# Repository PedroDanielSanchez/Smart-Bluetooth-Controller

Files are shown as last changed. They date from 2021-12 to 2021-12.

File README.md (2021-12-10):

# Smart-Bluetooth-Controller
Smart IoT Bluetooth sensors, scaling and integration gateway

# Smart Bluetooth Controller (Gateway) Asset tracking  
Smart IoT Bluetooth sensors, scaling and integration gateway

## Overview !

IoT applications that require scaling and multiple sensors several meters apart require the use of IoT gateways and integration with cloud apps and a local IoT Gateway aka controller. Bluetooth devices and beacons offer a variety of options and thus applications that allow scaling easily and cost-effectively. In this Smart IoT Bluetooth project I use different Bluetooth sensors in a system that can scale as needed. One application can be asset tracking using RSSI.

####  Features:
+ •	Measure valuable asset movement and send message if RSSI signal indicates it’s moving beyond a threshold with several asset tag sensors (Bluetooth sensors)
+•	Send notifications for RSSI if beacons move after a predefined value (Bluetooth sensors)
+•	Implement a Learning mode to register beacons to be tracked/monitored/observed
+•	Display (and refresh periodically) in a Dashboard the overall state of beacons: Total number of beacons, number of beacons that have gone into alarm state depending on a predefined value in dBm, number of beacons that have stopped to Advertise either because they’re far away, or they were stolen or the battery power drained
+•	Particle Argon for local controller
+•	OLED display
+•	GPS module to display current GPS location
+•	Button component to trigger learning (discovery) or normal operating mode.

Bluetooth devices broadcast services based upon their services. Usually asset locator BT devices broadcast every 6-8 seconds, but the time can be adjusted, and they don’t go into sleep mode. Therefore, the system will be constantly scanning for devices in the loop every 5 seconds to measure the RSSI and monitor the state of a beacon.

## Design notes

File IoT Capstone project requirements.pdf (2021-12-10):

IoT Capstone project

Smart IoT Bluetooth sensors Scaling and Integration

November 28, 2021 | Pedro D. Sanchez Amaro

Overview:

IoT applications that require scaling and multiple sensors several meters apart require the use of IoT gateways and integration with cloud apps and a local IoT controller. Bluetooth devices and beacons offer a variety of options and thus applications that allow scaling easily and costeffectively. In this Smart IoT Bluetooth project I use different Bluetooth sensors in a system that can scale as needed. One application can be asset tracking using RSSI.

Requirements:

- Measure valuable asset movement and send message if RSSI signal indicates it’s moving beyond a threshold with several asset tag sensors (Bluetooth sensors)
- Send notifications for RSSI if beacons move after a predefined value (Bluetooth sensors)
- Implement a Learning mode to register beacons to be tracked/monitored/observed.
- Display (and refresh periodically) in a Dashboard the overall state of beacons: Total number of beacons, number of beacons that have gone into alarm state depending on a predefined value in dBm, number of beacons that have stopped to Advertise either because they’re far away, or they were stolen or the battery power drained.
- Particle Argon for local controller
- OLED display
- GPS module to display current GPS location
- Button component to trigger learning (discovery) or normal operating mode.

Features:

Bluetooth devices broadcast services based upon their services. Usually asset locator BT devices broadcast every 6-8 seconds, but the time can be adjusted, and they don’t go into sleep mode. Therefore, the system will be constantly scanning for devices in the loop every 5 seconds to measure the RSSI and monitor the state of a beacon.

Implementation:

1. There will be a learning mode triggered by the push of a button to save in EEPROM the UUIDs of the beacons used so that if powered on/off, their UUIDs are there and furthermore, no other UUIDs are considered in the case that other Bluetooth devices are near passing by.
2. In the loop scan every SCAN_INTERVAL for a Bluetooth Advertising packet ( data ), look for the corresponding services and execute related callback.
a. Define an array of tracked assets (beacons), to keep track of their real time condition: stationary, moving, moving beyond a threshold system value (alarm state), non-advertising for a predefined time (“lost” state).
b. Define an array of beacon timers implemented with a class to keep
c. Use RSSI to estimate movements of assets tracked and notify global movements in OLED and publish movements depending on “objective”, send push notification to Mobile App in detail by beacon with the state that triggered the message, may sound a buzzer in the smartphone if necessary. RSSI is based in the signal strength (dBm is the unit of power for RSSI)
3. In the loop check GPS coordinates every 10 seconds, if it changed update position in DASHBOARD and send email or text message
4. Every predetermine system time display summary in Dashboard…
5. Optional: calculate and send ACx values of a Bluetooth beacon that supports it

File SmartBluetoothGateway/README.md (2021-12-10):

# SmartBluetoothGateway

A Particle project named SmartBluetoothGateway

## Welcome to your project!

Every new Particle project is composed of 3 important elements that you'll see have been created in your project directory for SmartBluetoothGateway.

#### ```/src``` folder:  
This is the source folder that contains the firmware files for your project. It should *not* be renamed. 
Anything that is in this folder when you compile your project will be sent to our compile service and compiled into a firmware binary for the Particle device that you have targeted.

If your application contains multiple files, they should all be included in the `src` folder. If your firmware depends on Particle libraries, those dependencies are specified in the `project.properties` file referenced below.

#### ```.ino``` file:
This file is the firmware that will run as the primary application on your Particle device. It contains a `setup()` and `loop()` function, and can be written in Wiring or C/C++. For more information about using the Particle firmware API to create firmware for your Particle device, refer to the [Firmware Reference](https://docs.particle.io/reference/firmware/) section of the Particle documentation.

#### ```project.properties``` file:  
This is the file that specifies the name and version number of the libraries that your project depends on. Dependencies are added automatically to your `project.properties` file when you add a library to a project using the `particle library add` command in the CLI or add a library in the Desktop IDE.

## Adding additional files to your project

#### Projects with multiple sources
If you would like add additional files to your application, they should be added to the `/src` folder. All files in the `/src` folder will be sent to the Particle Cloud to produce a compiled binary.

#### Projects with external libraries
If your project includes a library that has not been registered in the Particle libraries system, you should create a new folder named `/lib/<libraryname>/src` under `/<project dir>` and add the `.h`, `.cpp` & `library.properties` files for your library there. Read the [Firmware Libraries guide](https://docs.particle.io/guide/tools-and-features/libraries/) for more details on how to develop libraries. Note that all contents of the `/lib` folder and subfolders will also be sent to the Cloud for compilation.

## Compiling your project

When you're ready to compile your project, make sure you have the correct Particle device target selected and run `particle compile <platform>` in the CLI or click the Compile button in the Desktop IDE. The following files in your project folder will be sent to the compile service:

- Everything in the `/src` folder, including your `.ino` application file
- The `project.properties` file for your project
- Any libraries stored under `lib/<libraryname>/src`

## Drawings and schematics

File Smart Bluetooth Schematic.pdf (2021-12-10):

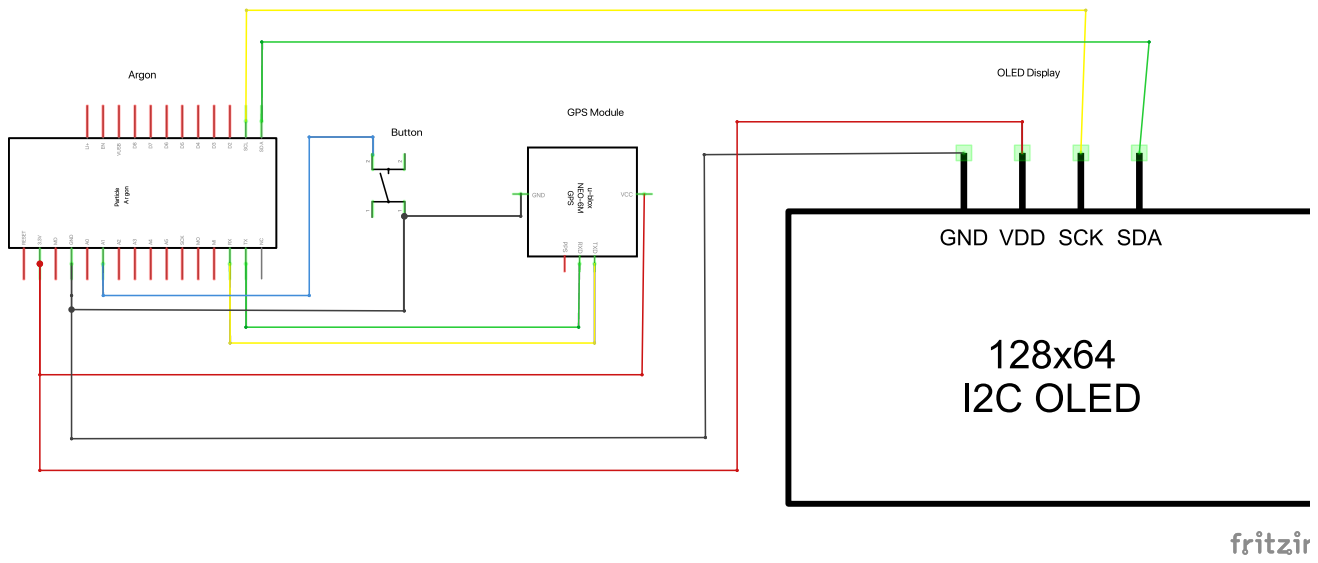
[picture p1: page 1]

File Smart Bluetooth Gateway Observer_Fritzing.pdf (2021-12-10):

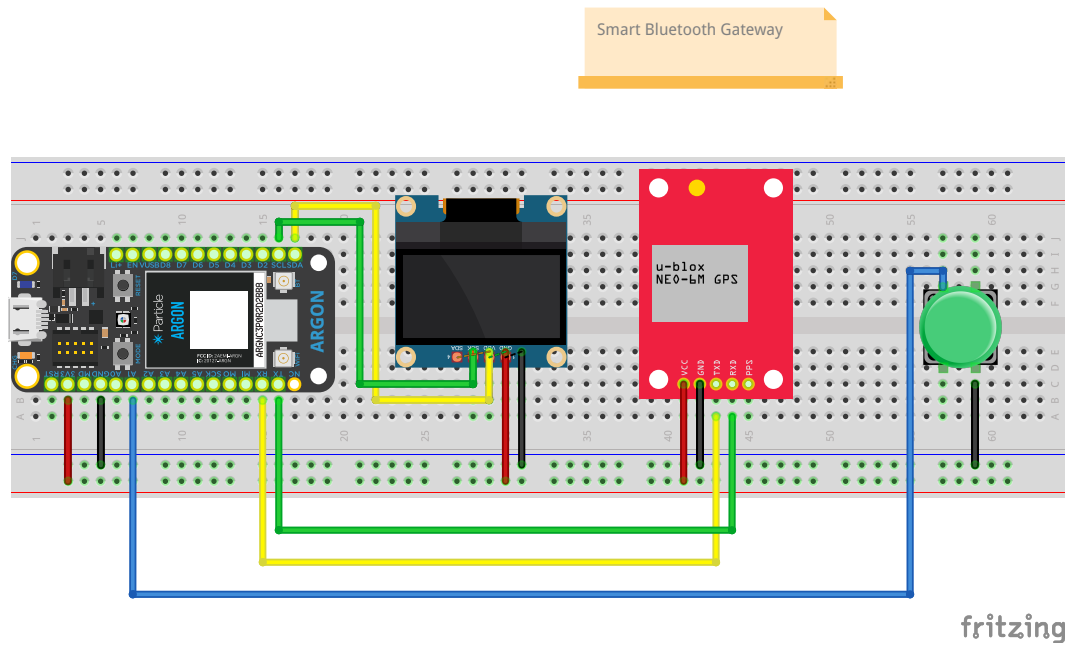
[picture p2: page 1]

Smart Bluetooth Gateway

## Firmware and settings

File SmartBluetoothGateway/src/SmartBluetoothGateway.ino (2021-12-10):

/*
 * Project Smart Bluetooth IoT Gateway/Controller 
 * Description: Track Multiple Beacons, notify Smartphones, register
 * *            in a learning mode, publish to Adafruit, report lost beacons
 * Author: Pedro Sanchez
 * Date: Nov 29 2021
 */


#include <math.h>
#include <Adafruit_MQTT.h>
#include "Adafruit_MQTT/Adafruit_MQTT.h"
#include "Adafruit_MQTT/Adafruit_MQTT_SPARK.h"
#include "Adafruit_GFX_RK.h"
#include "Adafruit_SSD1306_RK.h"
// #include "JsonParserGeneratorRK.h"
#include "IoT_Timer.h"
#include "TinyGPS++.h"
#include "credentials.h"

struct geo
{
  float lat;
  float lon;
};

#define OLED_RESET D4
Adafruit_SSD1306 display(OLED_RESET); // I2C oled display

TCPClient TheClient;

Adafruit_MQTT_SPARK mqtt(&TheClient, AIO_SERVER, AIO_SERVERPORT, AIO_USERNAME, AIO_KEY);

// Publish feeds
Adafruit_MQTT_Publish ACx = Adafruit_MQTT_Publish(&mqtt, AIO_USERNAME "/feeds/acx");
Adafruit_MQTT_Publish mTotalBeacons = Adafruit_MQTT_Publish(&mqtt, AIO_USERNAME "/feeds/totalbeacons");
Adafruit_MQTT_Publish mAlarmedBeacons = Adafruit_MQTT_Publish(&mqtt, AIO_USERNAME "/feeds/alarmedbeacons");
Adafruit_MQTT_Publish mLostBeacons = Adafruit_MQTT_Publish(&mqtt, AIO_USERNAME "/feeds/lostbeacons");

#define DASHBOARD_TIMING 40000 // publish every 40 seconds
#define TRACK_TIMEOUT_MS 30000 // beacon max timeout alarm is 30 seconds
#define GPS_READ_NTERVAL 120000 // 2 minutes for now... //  600000 for 10 minutes intervals
#define MAX_DEVICES 6

const int OLED_addr = 0x3C;

String DateTime, TimeOnly;

IoT_Timer pingMQQT;
IoT_Timer dashboardTimer;
IoT_Timer gpsReadTimer;

struct devicesBT
{
  char addrDev[20];
  char deviceName[20];
  int8_t deviceRSSI;
  byte deviceRSSIIndex;
  u_long deviceLastTime;
  time_t deviceLastTimeStr;
  byte status;
  byte alarmStatus;
};

void scanResultCallback(const BleScanResult *scanResult, void *context);

devicesBT trackedDevices[MAX_DEVICES]; // Tracking registered devices
IoT_Timer deviceTimers[MAX_DEVICES];   // Tracking if any beacon lost contact

// For logging use LOG as serial is not thread safe
SerialLogHandler logHandler(115200, LOG_LEVEL_ERROR, {{"app", LOG_LEVEL_TRACE}});

// https://btprodspecificationrefs.blob.core.windows.net/assigned-values/16-bit%20UUID%20Numbers%20Document.pdf

int totalFound = 0; // Beacons registered
int alarmedBeacons; // Beacons that have changed their RSSI
int lostBeacons;    // Beacons registered but not advertising
String devStatus;   // The payload going to the cloud
bool learningMode;  // Triggered with a button
bool lastLearningMode;

//---GPS variables ---//
TinyGPSPlus gps;
const int UTC_offset = -6;
float lat, lon, alt;
uint8_t hr, mn, se, sat, dy, mth, yr;

SYSTEM_MODE(AUTOMATIC);

void setup()
{

  // GPS  serial module   -> GND,Tx,Rx,Vcc
  // Module to Argon:  Rx => D9  Tx=> D10
  Serial1.begin(9600);

  Time.zone(-6);
  Particle.syncTime();

  learningMode = false;
  lastLearningMode = learningMode;
  delay(5000);
  pinMode(D7, OUTPUT);       // Test blue LED built-in
  pinMode(A0, INPUT_PULLUP); // Button
  attachInterrupt(A0, buttonHandler, FALLING);

  WiFi.connect();

  dashboardTimer.startTimer(DASHBOARD_TIMING);
  pingMQQT.startTimer(100);   // First time quick ping
  gpsReadTimer.startTimer(1); // 1st time read now

  // Initialize devices storage
  for (int i = 0; i < MAX_DEVICES; i++)
  {
    trackedDevices[i].status = 0;
    trackedDevices[i].alarmStatus = 0;
    trackedDevices[i].deviceLastTime = 0;
    trackedDevices[i].addrDev[0] = 0;
    trackedDevices[i].deviceRSSI = 0;
    trackedDevices[i].deviceRSSIIndex = 0;
    trackedDevices[i].deviceLastTimeStr = 0;
    strcpy(trackedDevices[i].deviceName, "");
    strcpy(trackedDevices[i].addrDev, "");
  }

  totalFound = 0;
  alarmedBeacons = 0;
  lostBeacons = 0;

  displaySetup(); // Initialize SSD1306 display
  updateOLED();
  BLE.setScanTimeout(500); // 5 secs as it's in 10ms increments
  Log.trace("Starting SMART BLUETOOTH RSSI Gateway");
}

void loop()
{

  DateTime = Time.timeStr();
  TimeOnly = DateTime.substring(11, 19);

  if (learningMode != lastLearningMode)
  { // Display operating mode
    lastLearningMode = learningMode;
    updateOLED();
  }

  if (gpsReadTimer.isTimerReady())
  {
    while (Serial1.available() > 0)
    {
      if (gps.encode(Serial1.read()))
      {
        Log.info("READ GPS location");
        saveGPSlocation(); // gps location is displayed later
      }
      else
      {
        Log.info("Cannot read GPS location");
      }
    }
    gpsReadTimer.startTimer(GPS_READ_NTERVAL); // update every 10 minutes
  }

  BLE.scan(scanResultCallback, NULL);

  MQTT_connect();
  keepAliveMQTT();

  //Log.trace("%s",DateTime.c_str());

  delay(2000);
  //BLE.scan(scanResultCallback, NULL);

  //Log.trace("%s", TimeOnly.c_str());

  for (int i = 0; i < totalFound; i++)
  {
    if (deviceTimers[i].isTimerReady())
    {
      // Check for a lost device (non Advertising) !
      if ((millis() - trackedDevices[i].deviceLastTime) > TRACK_TIMEOUT_MS)
      {
        Log.trace("%s [%i-%i] LOST device  #%i : %s  !!", TimeOnly.c_str(), totalFound, strlen(trackedDevices[i].addrDev), i, trackedDevices[i].addrDev);
        if (trackedDevices[i].status == 1)
        { // If it was active report "Not Advertising"
          // TBD Publish device not advertising to update the dashboard
          lostBeacons++;
        }

        devStatus = String::format("{\"beaconNum\":\"%i\",\"address\":\"%s\",\"lastSeen\":\"%s\",\"lastRSSI\":\"%i\",\"status\":\"%s\"}",
                                   i,
                                   trackedDevices[i].addrDev,
                                   Time.format(trackedDevices[i].deviceLastTimeStr, TIME_FORMAT_DEFAULT).c_str(),
                                   trackedDevices[i].deviceRSSI, "NOT ADVERTISING (LAST VALUES)");
        // Publish the RSSI and Device Info
        Log.trace("%s", devStatus.c_str());
        Particle.publish("status", devStatus, PRIVATE, WITH_ACK);
        trackedDevices[i].status = 0; // No advertising received
      }
      deviceTimers[i].startTimer(TRACK_TIMEOUT_MS);
    }
  }

  if (dashboardTimer.isTimerReady())
  {
    // Publish to dashboard
    updateOLED();
    if (mqtt.Update())
    {

      mAlarmedBeacons.publish(alarmedBeacons);
      mTotalBeacons.publish(totalFound);
      mLostBeacons.publish(lostBeacons);

      dashboardTimer.startTimer(DASHBOARD_TIMING); // reset the publish timer
    }
  }
}

void saveGPSlocation()
{

  Log.info("GPS valid: %d", gps.location.isValid());
  Log.info("GPS age  : %lu", gps.location.age());
  lat = gps.location.lat();
  lon = gps.location.lng();
  alt = gps.altitude.meters();
  hr = gps.time.hour();
  mn = gps.time.minute();
  se = gps.time.second();
  sat = gps.satellites.value();
  dy = gps.date.day();
  mth = gps.date.month();
  yr = gps.date.year();
  if (hr > 7)
  {
    hr = hr + UTC_offset;
  }
  else
  {
    hr = hr + 24 + UTC_offset;
  }
  Log.info("Lat: %f, Long: %f, Alt: %f \n", lat, lon, alt);
}

void displaySetup()
{
  display.begin(SSD1306_SWITCHCAPVCC, OLED_addr);
  display.display();
  delay(2000);
  display.clearDisplay();

  display.drawPixel(10, 10, WHITE);
  display.display();
  delay(2000);
  display.clearDisplay();
}

void updateOLED()
{
  display.setCursor(3, 0);
  display.clearDisplay();
  display.setTextSize(1);
  display.setTextColor(WHITE);
  display.printf("Smart Bluetooth IoT\n");
  if (!learningMode)
  {
    display.printf("Gateway NORMAL\n");
  }
  else
  {
    display.printf("Gateway LEARNING *\n");
  }
  display.printf("%s\n", TimeOnly.c_str());
  display.printf("Beacons     : %i\n", totalFound);
  display.printf("In Alarm    : %i\n", alarmedBeacons);
  display.printf("Lost Signal : %i\n", alarmedBeacons);
  display.printf("Lat: %.6f\n", lat);
  display.printf("Lon: %.6f\n", lon);
  display.display();
}

int deviceIsRegistered(const char *arr, int8_t rssi_val)
{

  if (memcmp(&arr[0], "AC:23", 4) != 0)
  {            // not equal to beacons PREFIX ?
    return -2; // device qill not be tracked
  }
  // Verify if already registered
  for (int i = 0; i < totalFound; i++)
  {
    if (strcmp(trackedDevices[i].addrDev, arr) == 0)
    { // found
      deviceTimers[i].startTimer(TRACK_TIMEOUT_MS);
      // Calculate if the device is moving based on RSSI ...
      if (abs(abs(trackedDevices[i].deviceRSSI) - abs(rssi_val)) >= 10)
      { // device is moving
        if (trackedDevices[i].alarmStatus == 0)
        {
          trackedDevices[i].alarmStatus = 1;
          alarmedBeacons++;
        }
      }
      else
      {
        if (trackedDevices[i].alarmStatus == 1)
        {
          trackedDevices[i].alarmStatus = 0;
          alarmedBeacons--;
        }
      }
      trackedDevices[i].deviceRSSI = rssi_val;
      trackedDevices[i].deviceLastTime = millis();
      trackedDevices[i].deviceLastTimeStr = Time.now();
      if (trackedDevices[i].status != 1)
      {
        lostBeacons--;
        devStatus = String::format("{\"beaconNum\":\"%i\",\"address\":\"%s\",\"lastSeen\":\"%s\",\"lastRSSI\":\"%i\",\"status\":\"%s\"}",
                                   i,
                                   trackedDevices[i].addrDev,
                                   Time.format(trackedDevices[i].deviceLastTimeStr, TIME_FORMAT_DEFAULT).c_str(),
                                   trackedDevices[i].deviceRSSI, "back in service");
        Log.trace("%s", devStatus.c_str());
        Particle.publish("status", devStatus, PRIVATE, WITH_ACK);

        //Process the publish event immediately
        Particle.process();

        trackedDevices[i].status = 1;
      }
      return i;
    }
  }
  // Check if it is a new one to register
  if (learningMode && (totalFound < MAX_DEVICES))
  {
    strcpy(trackedDevices[totalFound].addrDev, arr);
    trackedDevices[totalFound].status = 1;
    deviceTimers[totalFound].startTimer(TRACK_TIMEOUT_MS);
    trackedDevices[totalFound].deviceRSSI = rssi_val;
    trackedDevices[totalFound].deviceLastTime = millis();
    trackedDevices[totalFound].deviceLastTimeStr = Time.now();

    Log.trace("%s REGISTERED NEW device  #%i : %s  !!", TimeOnly.c_str(), totalFound, trackedDevices[totalFound].addrDev);
    devStatus = String::format("{\"beaconNum\":\"%i\",\"address\":\"%s\",\"lastSeen\":\"%s\",\"lastRSSI\":\"%i\",\"status\":\"%s\"}",
                               totalFound,
                               trackedDevices[totalFound].addrDev,
                               Time.format(trackedDevices[totalFound].deviceLastTimeStr, TIME_FORMAT_DEFAULT).c_str(),
                               trackedDevices[totalFound].deviceRSSI, "new device registered");
    // Publish the RSSI and Device Info
    Log.trace("%s", devStatus.c_str());
    Particle.publish("status", devStatus, PRIVATE, WITH_ACK);
    totalFound++;
    return totalFound - 1; // posicion del timer es 1 menos
  }
  return -1; // ** Array is full   AND/OR    ** Not in learningmode
}

void scanResultCallback(const BleScanResult *scanResult, void *context)
{

  uint8_t buffData[50];
  char tmpData[100];
  size_t dataLen;
  int posi = 0;
  uint8_t devRSSI;
  BleAddress beaconAddress;

  dataLen = scanResult->advertisingData.get(buffData, sizeof(buffData));

  beaconAddress = scanResult->address;
  devRSSI = scanResult->rssi;

  posi = deviceIsRegistered(beaconAddress.toString().c_str(), devRSSI);

  if (posi > -1)
  { // found
    Log.info("%s Target device => %i - %i <= found MAC: %s  RSSI: %ddBm [ %s ]", TimeOnly.c_str(), posi, totalFound, beaconAddress.toString().c_str(), scanResult->rssi,
             scanResult->advertisingData.deviceName().c_str());
    trackedDevices[posi].status = 1;

    memset(tmpData, 0, sizeof(tmpData));
    sprintf(tmpData, " %02x%02x Version Number %02x", buffData[5], buffData[6], buffData[12]);
    Log.info("%s", tmpData);

    if (buffData[5] == 0xe1 && buffData[6] == 0xff &&
        (buffData[12] == 0x03 || buffData[12] == 0x08))
    {
      processUuid(buffData, dataLen, posi);
    }
    memset(tmpData, 0, sizeof(tmpData));

    for (size_t j = 0; j < dataLen; j++)
    {
      sprintf(&tmpData[posi], "%02x", buffData[j]);
      posi += 2;
    }
    Log.info("%s", tmpData);

    BLE.stopScanning();
  }
}

void processUuid(uint8_t *myData, size_t len, int i)
{
  float xAxis;
  float intVal = 0;
  float decVal = 0;
  char devName[50];

  // Check for ACC-Axis Data

  if (myData[12] == 0x03)
  { // Confirm it's Axis data
    // conver hex with decimal in 2's complement to decimal
    intVal = myData[14];
    decVal = myData[15] / 256.0;
    xAxis = intVal > 127 ? ((intVal - 256) + decVal) : (intVal + decVal);
    Log.info("X-Axis = %.2f", xAxis);
  }
  else if (myData[12] == 0x08)
  {
    memset(devName, 0, sizeof(devName));
    memcpy(devName, &myData[20], len - 20);
    strcpy(trackedDevices[i].deviceName, devName);
  }
}

void buttonHandler()
{
  static system_tick_t lastButtonTime = 0;

  if ((millis() - lastButtonTime) > 500)
  {
    learningMode = !learningMode;
    lastButtonTime = millis();
  }
  if (learningMode)
  {
    digitalWrite(D7, HIGH);
    //totalFound = 0;
  }
  else
  {
    digitalWrite(D7, LOW);
  }
}

void MQTT_connect()
{
  int8_t ret;

  // Stop if already connected.
  if (mqtt.connected())
  {
    return;
  }

  Log.info("Connecting to MQTT... ");

  while ((ret = mqtt.connect()) != 0)
  { // connect will return 0 for connected
    Log.info("%s\n", (char *)mqtt.connectErrorString(ret));
    Log.info("Retrying MQTT connection in 5 seconds..\n");
    mqtt.disconnect();
    delay(5000); // wait 5 seconds
  }
  Log.info("MQTT Connected!\n");
}

void keepAliveMQTT()
{
  // Ping MQTT Broker every 2 minutes to keep connection alive
  if (pingMQQT.isTimerReady())
  {
    Log.info("Pinging MQTT \n");
    if (!mqtt.ping())
    {
      Log.info("Disconnecting \n");
      mqtt.disconnect();
    }
    pingMQQT.startTimer(120000);
  }
}

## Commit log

2021-12-10 moved and completed project
    [Smart Bluetooth Gateway Observer.fzz]
2021-12-10 adjuster gps refresh timer
